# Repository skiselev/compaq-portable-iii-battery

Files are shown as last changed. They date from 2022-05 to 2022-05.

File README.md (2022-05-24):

# Compaq Portable III Battery Module
Battery Module for Compaq Portable III

## Introduction

Battery module replacement for the Compaq Portable III using a CR2477N coin cell battery

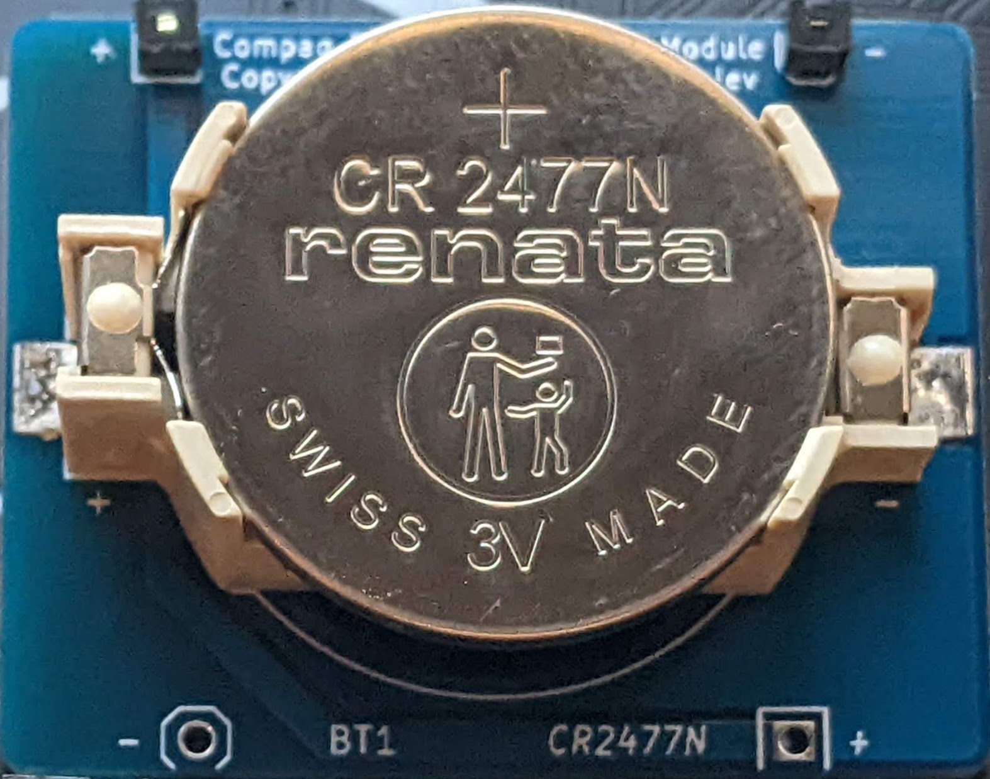
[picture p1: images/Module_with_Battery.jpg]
Module with Battery


### Schematic and PCB Layout

[Schematic](KiCad/Compaq_Portable_III_Battery-Schematic.pdf)

[PCB Layout](KiCad/Compaq_Portable_III_Battery-Board.pdf)

### Bill of Materials

[Compaq Portable III Battery Module project on Mouser.com](https://www.mouser.com/ProjectManager/ProjectDetail.aspx?AccessID=ce89cbe21a) - View and order all components except of the PCB.
[Compaq Portable III Battery Module  on OSH Park](https://oshpark.com/shared_projects/eMKmGV3U) - View and order the PCB.

Component type    	| Reference | Description                           | Quantity | Possible sources and notes 
------------------ | --------- | -------------------------------------- | -------- | --------------------------
PCB                |           | Compaq Portable III Battery Module PCB | 1        | Order from a PCB manufacturer of your choice using provided Gerber or KiCad files
Battery Holder     | BT1       | CR2477N coin cell battery holder       | 1        | Mouser [614-SMTU2477N-LF](https://www.mouser.com/ProductDetail/614-SMTU2477N-LF)
Battery            | BT1       | CR2477N coin cell battery              | 1        | Mouser [614-CR2477N.IB](https://www.mouser.com/ProductDetail/614-CR2477N.IB)
Pin Header         | J1-J4     | 1x1 pin header                         | 4        | 

### Assembly Notes

1. Solder pin headers first:
  * Insert the pin headers from the top side of the board "upside down", with the longer ends going through the PCB
  * Flip the board so the bottom side is on the top and place on an even surface
  * Make sure that the pin headers are perpendicular to the board
  * Carefully solder the pin headers, applying the solder and the soldering iron as close to the PCB as possible, avoiding any excess of solder on the pins
2. Solder the battery holder:
  * Tin the PCB pad with a small amount of solder
  * Place the battery holder on the PCB, observing the polarity: The + marking on the battery holder should match the + marking on the PCB
  * Heat the battery holder tabs with a tinned soldering iron, the solder should appear between the tabs and the PCB
3. Insert the battery

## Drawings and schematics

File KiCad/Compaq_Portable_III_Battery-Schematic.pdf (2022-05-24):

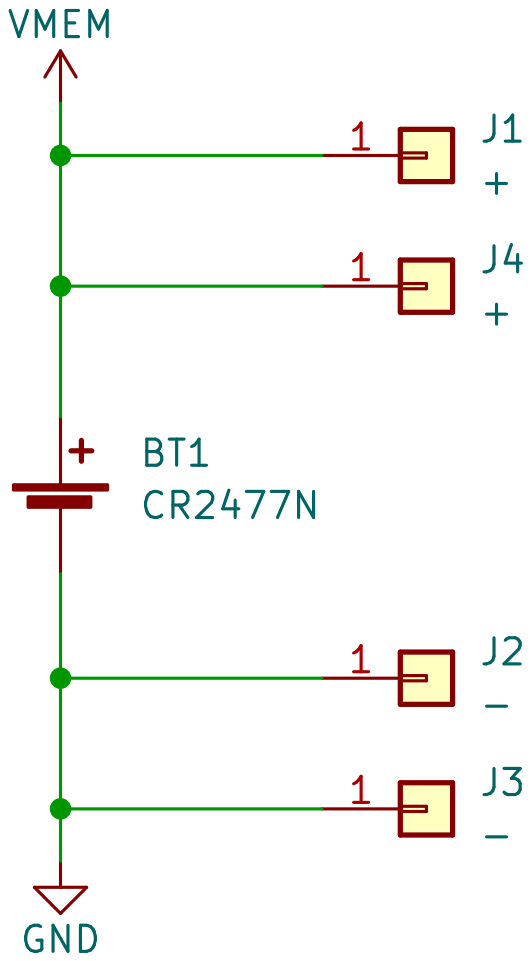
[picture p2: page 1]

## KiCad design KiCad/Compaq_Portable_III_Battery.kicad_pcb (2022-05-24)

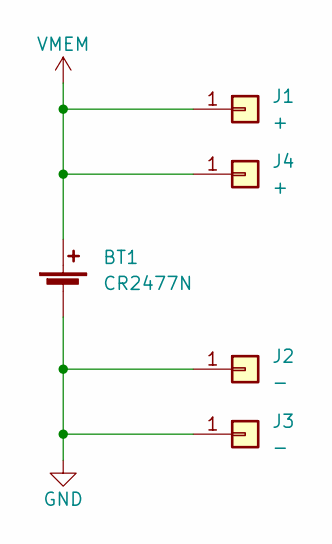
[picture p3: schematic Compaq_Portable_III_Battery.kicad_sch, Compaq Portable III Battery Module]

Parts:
BT1: CR2477N; Battery_Holder_Renata_SMTU2477N-LF_Hand_Soldering
J1, J4: +; Conn_Pin_Header_1x1_2.54mm
J2, J3: -; Conn_Pin_Header_1x1_2.54mm_NoKey

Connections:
GND: BT1.2 (-), J2.1, J3.1
VMEM: BT1.1 (+), J1.1, J4.1

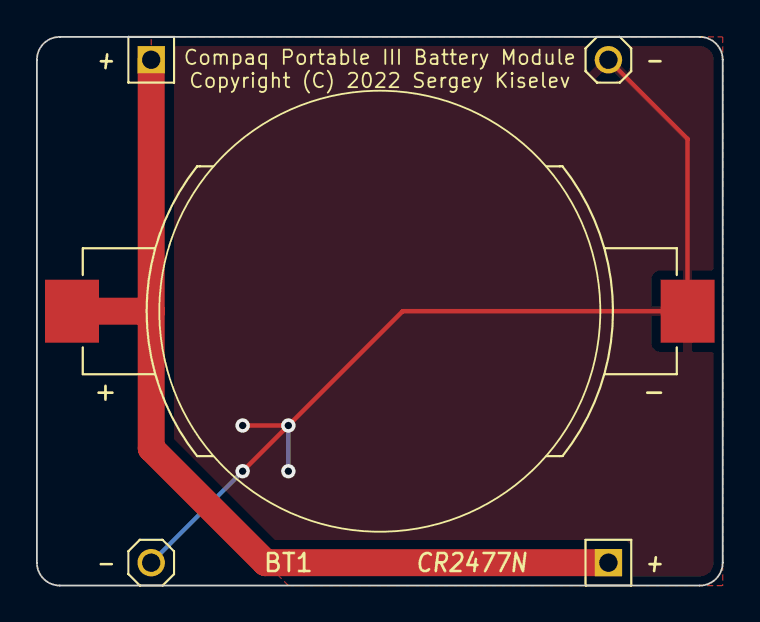
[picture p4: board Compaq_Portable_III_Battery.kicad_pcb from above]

Board: 2 copper layers, 38.1 x 30.5 mm, 5 parts (0 on the bottom side), 2 nets.

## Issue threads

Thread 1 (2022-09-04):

Charge Protection.

raymondh2, 2022-09-04:
It seems some revisions of the Compaq Portable III maainboard have a charging circuit. Some being included would be nice to see at a later time.

skiselev, 2022-09-06:
I am not sure I am familiar with that type of Compaq Portable III
From [this description](http://minuszerodegrees.net/manuals/Compaq/Compaq%20Portable%20III%20-%20CMOS%20battery%20-%20options.htm) it appears that there are two options:
1. External battery, that's exactly what this project is intended to replace. The extra components on the motherboard in this case are battery switchover circuit, and not charging circuit
2. Dallas DS1287 RTC module, which includes a built-in battery. In this case, the motherboard will have a few zero ohm links.

If the option that you're referring to is yet another option, I'd appreciate more information on it (e.g., motherboard photos)

raymondh2, 2022-09-09:
It's the first type. Here the system is on
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
Here the system is off.
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

skiselev, 2022-09-12:
Not sure what I see here. Does it try to charge the battery?
It uses a primary battery, so it shouldn't be charged.

Closed 2022-09-12.

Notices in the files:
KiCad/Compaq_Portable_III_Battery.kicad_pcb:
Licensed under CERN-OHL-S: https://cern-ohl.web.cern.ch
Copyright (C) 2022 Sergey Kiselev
